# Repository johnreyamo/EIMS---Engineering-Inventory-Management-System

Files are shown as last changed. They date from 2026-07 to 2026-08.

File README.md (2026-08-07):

# Engineering Inventory Management System (EIMS)

## 📌 Project Overview
The Engineering Inventory Management System (EIMS) is a hardware and software solution designed to track the borrowing and returning of registered workshop tools across multiple cabinets in real time. Powered by an ESP32 microcontroller and an MFRC522 RFID scanner, the system logs physical tag scans and syncs them to a locally hosted web dashboard for seamless monitoring, administration, and history tracking.

## ✨ Key Features
*   **Dual Operation Modes:** Hardware switch to toggle between User Mode (borrow/return) and Admin Mode (registration/management).
*   **RFID Integration:** Fast and secure tool tracking and engineer login using MFRC522.
*   **Standalone Wi-Fi Access Point:** Hosts its own network and web dashboard—no external internet connection required.
*   **Real-time Web Dashboard:** Live UI updates, tool search, dynamic cabinet carousels, and bulk management.
*   **Automated Logging & Export:** Tracks all transactions and sessions, automatically groups them weekly, and allows CSV exports.
*   **Failsafe Local Storage:** Uses JSON file storage on the ESP32 flash memory with automatic `.bak` backups to prevent data corruption.
*   **Visual & Audio Feedback:** Integrated NeoPixel LED and Buzzer for scan confirmations and error alerts.

---

## 🛠️ Hardware Specifications & Pinout

This project is built using an **ESP32-S3** (or standard ESP32) with the following pin configurations:

| Component | ESP32 Pin |
| :--- | :--- |
| **MFRC522 SCK** | GPIO 14 |
| **MFRC522 MOSI** | GPIO 13 |
| **MFRC522 MISO** | GPIO 12 |
| **MFRC522 RST** | GPIO 9 |
| **MFRC522 CS** | GPIO 10 |
| **NeoPixel LED** | GPIO 38 |
| **RGB RED** | GPIO 17 |
| **RGB BLUE** | GPIO 15 |
| **RGB GREEN** | GPIO 7 |
| **Buzzer** | GPIO 6 |
| **Admin/User Switch** | GPIO 4 (Uses internal Pull-Up) |

---

## 🚀 Network & Access

Upon powering the ESP32, it will broadcast its own Wi-Fi network.
*   **Network SSID:** `EIMS - ESP32`
*   **Password:** `12345678`
*   **Dashboard Access:** Open a web browser and navigate to the IP address assigned by the ESP32 (typically `http://192.168.4.1`).
*   **Default Admin Credentials:** Username: `admin` | Password: `123`

---

## 📖 How to Use

### 1. User Mode (Borrowing & Returning)
Ensure the physical hardware switch is flipped to **User Mode**.
*   **Login:** Tap a registered Engineer ID card on the scanner to start a session. 
*   **Borrow/Return:** Tap an available tool tag to borrow it. Tap a borrowed tool tag again to return it.
*   **Transfer:** If another engineer needs a tool you currently have, they can tap their ID card to take over the session, then tap the tool to transfer it into their name.
*   **Logout:** Tap your Engineer ID card again, or wait for the automatic inactivity timeout (default is 10 seconds).

### 2. Admin Mode (Registration & Management)
Flip the physical hardware switch to **Admin Mode** and log in to the web dashboard.
*   **Registration:** Enter the new Tool or Engineer details in the dashboard and click "Add". The system will enter standby mode. Tap a blank RFID tag on the physical scanner to burn the data and complete the registration.
*   **Bulk Management:** Use the dashboard to select multiple tools to move them between cabinets, change their storage layers, mark them inactive, or delete them.
*   **History & Reports:** Navigate to the "History" tab to view recent transactions and download complete weekly CSV logs for both tools and user sessions.

---

## ⚙️ System Settings & Data Management
The web dashboard includes a settings menu that allows the administrator to:
*   Update admin login credentials.
*   Adjust inactivity timeout durations for both users and admins.
*   Toggle physical buzzer feedback on or off.
*   Download full database backups or restore the system from a previous JSON backup file.
*   Purge old history logs to free up flash storage or perform a complete Factory Reset.S

## Note!!
* This inventory system is not finish.
* When making the code name main.py to run it by just using a charger, the devices can't access the webserver.

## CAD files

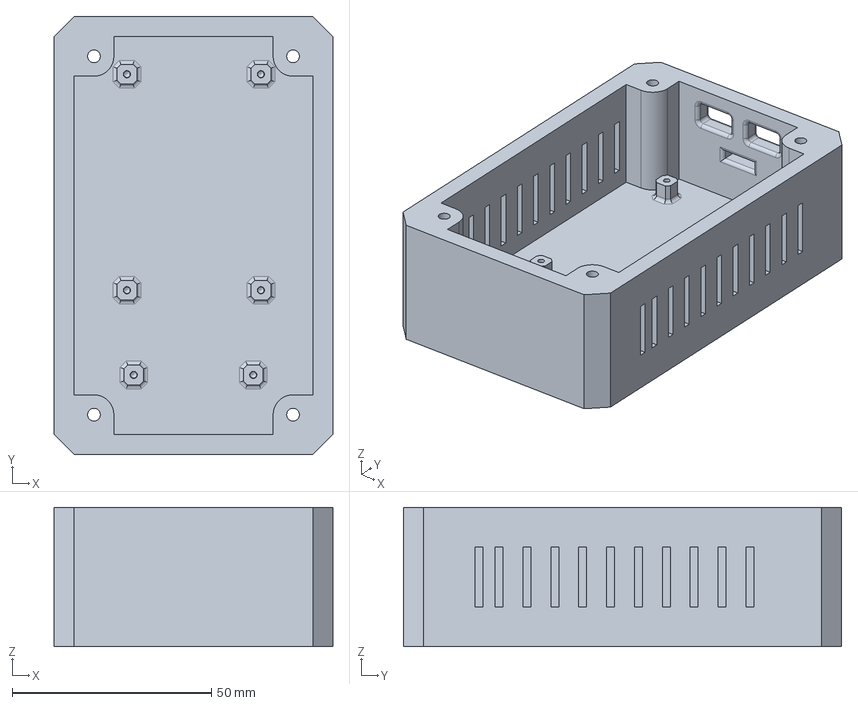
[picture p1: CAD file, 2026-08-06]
esp_buzzer_v2.FCStd
70.0 x 110.0 x 35.0 mm

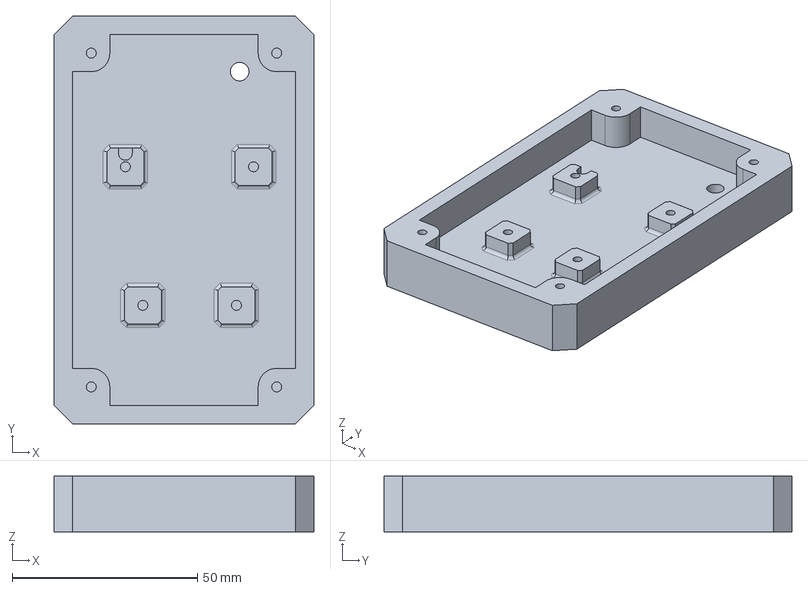
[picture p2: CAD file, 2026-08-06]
RC522_LED_v2.FCStd
70.0 x 110.0 x 15.0 mm

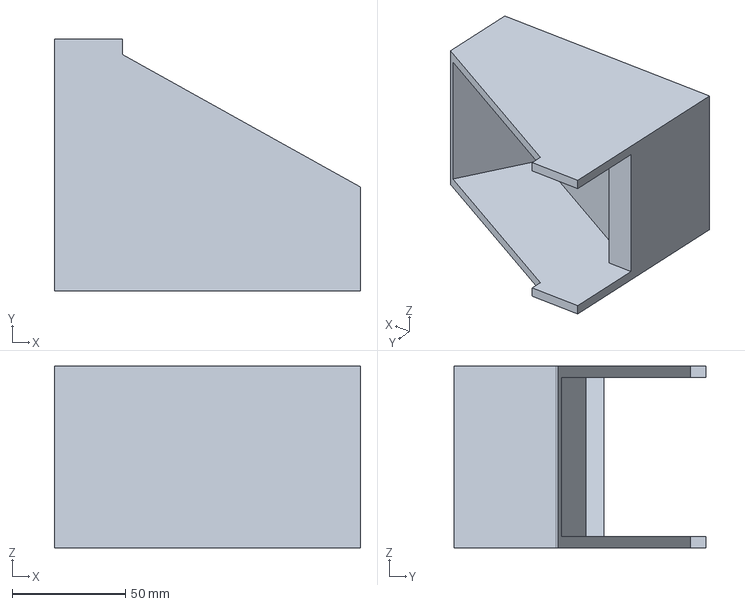
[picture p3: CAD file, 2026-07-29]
Patungan_ng_enclosure.FCStd
135.0 x 111.3 x 80.2 mm

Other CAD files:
esp_buzzer_2nd_Copy.FCStd
RC522_LED.FCStd

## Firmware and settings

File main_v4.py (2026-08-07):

import network
import time
import json
import os
import uasyncio as asyncio
import machine
import neopixel
import sys
import uhashlib
import ubinascii
import gc
from machine import Pin
from mfrc522 import MFRC522

# ==========================================
# 1. CONFIG & HARDWARE DEFINITIONS
# ==========================================
SESSION_TIMEOUT           = 10
ADMIN_SESSION_TIMEOUT     = 60
SWITCH_DEBOUNCE_MS        = 50
DASHBOARD_WIDTH           = 72
MAX_TOOLS_PER_PAGE        = 10
BUZZER_PIN                = 5
SWITCH_PIN                = 4

SWITCH_CONFIRM_WINDOW_MS  = 5000   
TAG_MISS_THRESHOLD        = 2      
PENDING_TAG_MISS_THRESHOLD = 1      

NORMAL_SCAN_INTERVAL_MS   = 40     
FAST_SCAN_INTERVAL_MS     = 15     

led = machine.Pin(38, machine.Pin.OUT)
px = neopixel.NeoPixel(led, 1)
buzzer = machine.Pin(BUZZER_PIN, machine.Pin.OUT)
mode_switch = machine.Pin(SWITCH_PIN, machine.Pin.IN, machine.Pin.PULL_UP)

red = Pin(16, Pin.OUT)
green = Pin(6, Pin.OUT)
blue = Pin(7, Pin.OUT)


# --- HARDWARE RESET SEQUENCE ---
reader = None
def init_scanner():
    print("[HARDWARE] Initializing MFRC522 Scanner...")
    try:
        for pin_num in [14, 13, 12, 10, 9]:
            try:
                machine.Pin(pin_num, machine.Pin.IN)
            except:
                pass
        time.sleep_ms(50)

        rfid_rst = machine.Pin(9, machine.Pin.OUT)
        rfid_rst.value(0)
        time.sleep_ms(150)  
        rfid_rst.value(1)
        time.sleep_ms(150)

        rdr = MFRC522(sck=14, mosi=13, miso=12, rst=9, cs=10)
        
        if hasattr(rdr, 'init'):
            rdr.init()
        if hasattr(rdr, 'stop_crypto1'):
            rdr.stop_crypto1()
            
        print("[HARDWARE] MFRC522 Scanner online.")
        return rdr
    except Exception as e:
        print(f"[CRITICAL] MFRC522 driver failed to init: {e}")
        return None

reader = init_scanner()

_switch_last_reading = mode_switch.value()
_switch_stable_value = _switch_last_reading
_switch_last_change_ms = time.ticks_ms()

def get_stable_switch():
    global _switch_last_reading, _switch_stable_value, _switch_last_change_ms
    current = mode_switch.value()
    if current != _switch_last_reading:
        _switch_last_reading = current
        _switch_last_change_ms = time.ticks_ms()
    elif time.ticks_diff(time.ticks_ms(), _switch_last_change_ms) > SWITCH_DEBOUNCE_MS:
        _switch_stable_value = current
    return _switch_stable_value

# ==========================================
# 2. DATABASE & GLOBAL STATE
# ==========================================
def _load_backup_or_empty(filename):
    backup_name = filename + ".bak"
    try:
        with open(backup_name, "r") as file:
            return json.load(file)
    except (OSError, ValueError):
        return {}

def load_database(filename):
    try:
        with open(filename, "r") as file:
            return json.load(file)
    except OSError:
        return _load_backup_or_empty(filename)
    except ValueError:
        return _load_backup_or_empty(filename)

def save_database(filename, data):
    tmp_name = filename + ".tmp"
    bak_name = filename + ".bak"
    try:
        with open(tmp_name, "w") as file:
            json.dump(data, file)
        try:
            os.rename(filename, bak_name)
        except OSError:
            pass
        os.rename(tmp_name, filename)
    except OSError as e:
        print(f"[ERROR] Failed to save {filename}: {e}")

async def save_database_async(filename, data, yield_every=15):
    """Same as save_database, but yields to the event loop every N records
    so a big history/session/inventory file doesn't block RFID scans or
    HTTP responses while it's being written."""
    tmp_name = filename + ".tmp"
    bak_name = filename + ".bak"
    try:
        with open(tmp_name, "w") as file:
            if isinstance(data, list):
                file.write("[")
                for i, item in enumerate(data):
                    if i:
                        file.write(",")
                    file.write(json.dumps(item))
                    if i % yield_every == 0:
                        await asyncio.sleep_ms(0)
                file.write("]")
            elif isinstance(data, dict):
                file.write("{")
                for i, (k, v) in enumerate(data.items()):
                    if i:
                        file.write(",")
                    file.write(json.dumps(k) + ":" + json.dumps(v))
                    if i % yield_every == 0:
                        await asyncio.sleep_ms(0)
                file.write("}")
            else:
                json.dump(data, file)
        try:
            os.rename(filename, bak_name)
        except OSError:
            pass
        os.rename(tmp_name, filename)
    except OSError as e:
        print(f"[ERROR] Failed to save {filename}: {e}")

DB_FLUSH_IDLE_DELAY_MS = 2000
_dirty_files = {}  
_db_flush_timer = 0
_last_gc_ms = 0
GC_MIN_INTERVAL_MS = 5000

def mark_dirty(filename, data):
    global _db_flush_timer
    _dirty_files[filename] = data
    _db_flush_timer = time.ticks_ms() + DB_FLUSH_IDLE_DELAY_MS

async def db_flush_task():
    global _dirty_files, _db_flush_timer, _last_gc_ms
    while True:
        await asyncio.sleep_ms(300)
        if _dirty_files and time.ticks_diff(time.ticks_ms(), _db_flush_timer) > 0:
            pending = _dirty_files
            _dirty_files = {}
            for fname, data in pending.items():
                await save_database_async(fname, data)
                await asyncio.sleep_ms(10) 
            now = time.ticks_ms()
            if time.ticks_diff(now, _last_gc_ms) > GC_MIN_INTERVAL_MS:
                gc.collect()
                _last_gc_ms = now

def hash_password(password):
    digest = uhashlib.sha256(password.encode('utf-8')).digest()
    return ubinascii.hexlify(digest).decode()

def get_header_value(headers_str, header_name):
    prefix = header_name.lower() + ":"
    for line in headers_str.split('\r\n'):
        if line.lower().startswith(prefix):
            return line.split(":", 1)[1].strip()
    return None

def generate_session_token():
    return ubinascii.hexlify(os.urandom(16)).decode()

def _migrate_users_db(users):
    changed = False
    for uid, val in list(users.items()):
        if isinstance(val, str):
            users[uid] = {"name": val, "status": "Registered"}
            changed = True
    return users, changed

def _migrate_inventory_active(tools):
    changed = False
    for tid, info in tools.items():
        if isinstance(info, dict) and "active" not in info:
            info["active"] = True
            changed = True
    return changed

def _migrate_cabinets(inv):
    changed = False
    if "cabinets" not in inv:
        inv["cabinets"] = [
            {"id": "1", "name": "Cabinet 1"},
            {"id": "2", "name": "Cabinet 2"},
            {"id": "3", "name": "Cabinet 3"}
        ]
        changed = True
    return changed

inventory_db = load_database("inventory.json")
users_db = load_database("users.json")
admins_db = load_database("admins.json")

system_settings = load_database("settings.json")
if not system_settings:
    # Default settings if the file doesn't exist yet
    system_settings = {"session_timeout": 10, "admin_timeout": 60}
    save_database("settings.json", system_settings)
    
SESSION_TIMEOUT = system_settings.get("session_timeout", 10)
ADMIN_SESSION_TIMEOUT = system_settings.get("admin_timeout", 60)
BUZZER_ENABLED = system_settings.get("buzzer_enabled", True)

# Overwrite the global timeout variables with the saved settings
SESSION_TIMEOUT = system_settings.get("session_timeout", 10)
ADMIN_SESSION_TIMEOUT = system_settings.get("admin_timeout", 60)

if "tools" not in inventory_db:
    inventory_db = {"tools": inventory_db}

mig1 = _migrate_inventory_active(inventory_db["tools"])
mig2 = _migrate_cabinets(inventory_db)
if mig1 or mig2:
    save_database("inventory.json", inventory_db)

users_db, _users_changed = _migrate_users_db(users_db)
if _users_changed:
    save_database("users.json", users_db)

if not admins_db:
    admins_db = {"admin": hash_password("123")}
    save_database("admins.json", admins_db)

def get_history_filename():
    y, m, d, h, mi, s, wday, yday = time.localtime()
    return f"history_{y}_{m:02d}_{d:02d}.json"

current_history_filename = get_history_filename()
history_db = load_database(current_history_filename)
if not isinstance(history_db, list):
    history_db = []

current_session_filename = get_history_filename().replace("history_", "sessions_")
session_history_db = load_database(current_session_filename)
if not isinstance(session_history_db, list):
    session_history_db = []

current_session_entry = None

def check_day_rollover():
    """Swaps history_db/session_history_db to a new file once the calendar
    day changes. Keeping this on a daily boundary (instead of weekly) bounds
    how many entries stay resident in RAM and how large each save-to-flash
    rewrite gets, since save_database_async rewrites the full list on every
    flush."""
    global history_db, current_history_filename
    global session_history_db, current_session_filename
    new_filename = get_history_filename()
    if new_filename != current_history_filename:
        current_history_filename = new_filename
        history_db = load_database(new_filename)
        if not isinstance(history_db, list):
            history_db = []
    new_session_filename = new_filename.replace("history_", "sessions_")
    if new_session_filename != current_session_filename:
        current_session_filename = new_session_filename
        session_history_db = load_database(new_session_filename)
        if not isinstance(session_history_db, list):
            session_history_db = []

def log_borrow(tool_id, tool_name, borrower_name):
    global history_db, current_history_filename
    check_day_rollover()
    y, m, d, h, mi, s, _, _ = time.localtime()
    date_str = f"{m:02d}/{d:02d}/{y}"
    time_str = f"{h:02d}:{mi:02d}"
    control_no = f"TX{y}{m:02d}{d:02d}{h:02d}{mi:02d}{s:02d}"

    entry = {
        "control_no": control_no, "tool_id": tool_id, "tool_name": tool_name,
        "borrowed_by": borrower_name, "date": date_str, "time_borrow": time_str,
        "time_return": "", "status_note": ""
    }
    history_db.append(entry)
    mark_dirty(current_history_filename, history_db)

def log_return(tool_id):
    global history_db, current_history_filename
    check_day_rollover()
    y, m, d, h, mi, s, _, _ = time.localtime()
    time_str = f"{h:02d}:{mi:02d}"

    for entry in reversed(history_db):
        if entry.get("tool_id") == tool_id and not entry.get("time_return"):
            entry["time_return"] = time_str
            mark_dirty(current_history_filename, history_db)
            break

def log_transfer(tool_id, tool_name, previous_holder, new_holder):
    global history_db, current_history_filename
    check_day_rollover()
    y, m, d, h, mi, s, _, _ = time.localtime()
    date_str = f"{m:02d}/{d:02d}/{y}"
    time_str = f"{h:02d}:{mi:02d}"

    for entry in reversed(history_db):
        if entry.get("tool_id") == tool_id and not entry.get("time_return"):
            entry["time_return"] = time_str
            entry["status_note"] = f"Transferred to {new_holder}"
            break

    control_no = f"TX{y}{m:02d}{d:02d}{h:02d}{mi:02d}{s:02d}"
    entry = {
        "control_no": control_no, "tool_id": tool_id, "tool_name": tool_name,
        "borrowed_by": new_holder, "date": date_str, "time_borrow": time_str,
        "time_return": "", "status_note": f"Transferred from {previous_holder}"
    }
    history_db.append(entry)
    mark_dirty(current_history_filename, history_db)

def log_session_start(borrower_id, borrower_name):
    global session_history_db, current_session_filename, current_session_entry
    check_day_rollover()
    y, m, d, h, mi, s, _, _ = time.localtime()
    date_str = f"{m:02d}/{d:02d}/{y}"
    time_str = f"{h:02d}:{mi:02d}:{s:02d}"
    control_no = f"SX{y}{m:02d}{d:02d}{h:02d}{mi:02d}{s:02d}"

    entry = {
        "control_no": control_no, "borrower_id": borrower_id, "borrowed_by": borrower_name,
        "date": date_str, "login_time": time_str, "logout_time": "", "items": []
    }
    session_history_db.append(entry)
    current_session_entry = entry
    mark_dirty(current_session_filename, session_history_db)

def log_session_item(tool_id, tool_name, status):
    global current_session_entry
    if current_session_entry is None:
        return
    check_day_rollover()
    y, m, d, h, mi, s, _, _ = time.localtime()
    time_str = f"{h:02d}:{mi:02d}"
    current_session_entry["items"].append({
        "tool_id": tool_id, "name": tool_name, "time": time_str, "status": status
    })
    mark_dirty(current_session_filename, session_history_db)

def log_session_end():
    global current_session_entry
    if current_session_entry is None:
        return
    y, m, d, h, mi, s, _, _ = time.localtime()
    time_str = f"{h:02d}:{mi:02d}:{s:02d}"
    current_session_entry["logout_time"] = time_str
    mark_dirty(current_session_filename, session_history_db)
    current_session_entry = None

admin_session_active = False
admin_session_token = None
admin_last_activity_time = time.ticks_ms()
pending_registration = None
last_registration_result = None

active_borrower_id = None
active_borrower_name = None
last_activity_time = time.ticks_ms()
current_cabinet_id = "1"
terminal_message = "Please tap your ID card to begin..."

scan_event_seq = 0
scan_event_time = 0
pending_switch_id = None
pending_switch_time = 0

def get_short_timestamp():
    y, m, d, h, mi, s, _, _ = time.localtime()
    return f"{m:02d}/{d:02d} {h:02d}:{mi:02d}"

def _parse_hms(t):
    parts = [int(x) for x in t.split(":")]
    while len(parts) < 3:
        parts.append(0)  # handles old HH:MM entries with no seconds
    h, m, s = parts[0], parts[1], parts[2]
    return h * 3600 + m * 60 + s

def format_duration(login_time, logout_time):
    if not login_time or not logout_time:
        return ""
    try:
        total_seconds = _parse_hms(logout_time) - _parse_hms(login_time)
    except (ValueError, AttributeError):
        return ""
    if total_seconds < 0:
        total_seconds += 24 * 3600  # session crossed midnight
    h, rem = divmod(total_seconds, 3600)
    m, s = divmod(rem, 60)
    if h:
        return f"{h}h {m}m {s}s"
    if m:
        return f"{m}m {s}s"
    return f"{s}s"

def natural_sort_key(s):
    key = []
    num = ""
    for ch in s:
        if ch.isdigit():
            num += ch
        else:
            if num:
                key.append((1, int(num)))
                num = ""
            key.append((0, ch.lower()))
    if num:
        key.append((1, int(num)))
    return key

def sort_tool_entries(entries):
    return sorted(
        entries,
        key=lambda pair: (pair[1].get("status", "Available") == "Available", natural_sort_key(pair[0]))
    )

def emit_terminal_message(msg):
    global terminal_message, scan_event_seq, scan_event_time
    terminal_message = msg
    scan_event_seq += 1
    scan_event_time = time.ticks_ms()
    request_dashboard_render()

# ==========================================
# 3. ASYNC VISUAL CUES (NON-BLOCKING)
# ==========================================
_active_feedback_task = None

def clear_led():
    px[0] = (0, 0, 0)
    px.write()
    red.value(1)
    green.value(1)
    blue.value(1)

async def blink_success():
    for _ in range(1):
        px[0] = (0, 255, 0)
        px.write()
        green.value(0)
        if BUZZER_ENABLED: buzzer.value(1)
        await asyncio.sleep_ms(60)
        clear_led()
        buzzer.value(0)
        await asyncio.sleep_ms(60)

async def blink_error():
    for _ in range(1):
        px[0] = (255, 0, 0)
        px.write()
        red.value(0)
        if BUZZER_ENABLED: buzzer.value(1)
        await asyncio.sleep_ms(60)
        clear_led()
        buzzer.value(0)
        await asyncio.sleep_ms(60)

async def hold_led_blue():
    px[0] = (0, 0, 255)
    blue.value(0)
    px.write()
    if BUZZER_ENABLED: buzzer.value(1)
    await asyncio.sleep_ms(60)
    buzzer.value(0)

def start_feedback(coro):
    global _active_feedback_task
    if _active_feedback_task is not None and not _active_feedback_task.done():
        try:
            _active_feedback_task.cancel()
        except Exception:
            pass
        clear_led()
        buzzer.value(0)
    _active_feedback_task = asyncio.create_task(coro)
    return _active_feedback_task

async def switch_pending_watchdog(expected_id):
    global pending_switch_id
    await asyncio.sleep_ms(SWITCH_CONFIRM_WINDOW_MS)
    if pending_switch_id == expected_id:
        pending_switch_id = None
        clear_led()
        emit_terminal_message("[ERROR] Session switch timed out.")

# ==========================================
# 4. TERMINAL DASHBOARD LOGIC
# ==========================================
DASHBOARD_RENDER_INTERVAL_MS = 120
DASHBOARD_WRITE_CHUNK_SIZE = 256
_dashboard_dirty = True  

def request_dashboard_render():
    global _dashboard_dirty
    _dashboard_dirty = True

async def dashboard_render_task():
    global _dashboard_dirty
    while True:
        if _dashboard_dirty:
            _dashboard_dirty = False
            await write_terminal_dashboard()
        await asyncio.sleep_ms(DASHBOARD_RENDER_INTERVAL_MS)

def pad_center(text, width):
    text = str(text)
    if len(text) >= width: return text[:width]
    total_pad = width - len(text)
    left = total_pad // 2
    return " " * left + text + " " * (total_pad - left)

def build_terminal_dashboard():
    global current_cabinet_id, terminal_message, active_borrower_name, admin_session_active, pending_registration

    lines = []
    bar = "=" * DASHBOARD_WIDTH
    lines.append(bar)

    if get_stable_switch() == 0:
        lines.append(pad_center("ADMIN MODE - TAG/CARD REGISTRATION", DASHBOARD_WIDTH))
        lines.append(bar)
        if admin_session_active:
            if pending_registration:
                lines.append("")
                lines.append(pad_center("> READY TO WRITE <", DASHBOARD_WIDTH))
                lines.append(pad_center(f"ID to burn: {pending_registration['id']}", DASHBOARD_WIDTH))
                lines.append(pad_center("Tap the new card or tag now...", DASHBOARD_WIDTH))
                lines.append("")
            else:
                lines.append("")
                lines.append(pad_center("SYSTEM STANDBY", DASHBOARD_WIDTH))
                lines.append(pad_center("Enter details on the web dashboard and click Add.", DASHBOARD_WIDTH))
                lines.append("")
                lines.append("")
        else:
            lines.append("")
            lines.append(pad_center("NO ADMIN LOGGED IN", DASHBOARD_WIDTH))
            lines.append(pad_center("Log in on the web dashboard to enable writing.", DASHBOARD_WIDTH))
            lines.append("")
            lines.append("")
        lines.append("-" * DASHBOARD_WIDTH)
        lines.append(f" > {terminal_message}")

    else:
        cabs = inventory_db.get("cabinets", [])
        cab_name = "Unknown Cabinet"
        for c in cabs:
            if str(c["id"]) == str(current_cabinet_id):
                cab_name = c["name"]
                break
                
        lines.append(pad_center(f"WORKSHOP INVENTORY - {cab_name.upper()}", DASHBOARD_WIDTH))
        lines.append(bar)

        user_disp = f"[{active_borrower_name}]" if active_borrower_name else "[LOCKED]"
        lines.append(pad_center(user_disp, DASHBOARD_WIDTH))
        lines.append("-" * DASHBOARD_WIDTH)

        tools = inventory_db.get("tools", {})
        cab_tools = sort_tool_entries(
            [(tid, info) for tid, info in tools.items()
             if str(info.get("cabinet", "1")) == str(current_cabinet_id) and info.get("active", True)]
        )

        for i in range(MAX_TOOLS_PER_PAGE):
            if i < len(cab_tools):
                t_id, info = cab_tools[i]
                name = info.get("name", "?")[:20]
                status = info.get("status", "Available")
                lines.append(f" {t_id:<8} | {name:<20} | {status}")
            else:
                lines.append(" ")

        lines.append("-" * DASHBOARD_WIDTH)
        lines.append(f" > {terminal_message}")
    lines.append(bar)

    return "\x1b[2J\x1b[H" + "\n".join(lines) + "\n"

async def write_terminal_dashboard():
    output = build_terminal_dashboard()
    for i in range(0, len(output), DASHBOARD_WRITE_CHUNK_SIZE):
        sys.stdout.write(output[i:i + DASHBOARD_WRITE_CHUNK_SIZE])
        await asyncio.sleep_ms(0)
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
